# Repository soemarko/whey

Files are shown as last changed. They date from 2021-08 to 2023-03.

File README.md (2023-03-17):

# Whey v2.0

DIY coffee scale / load cell controller.

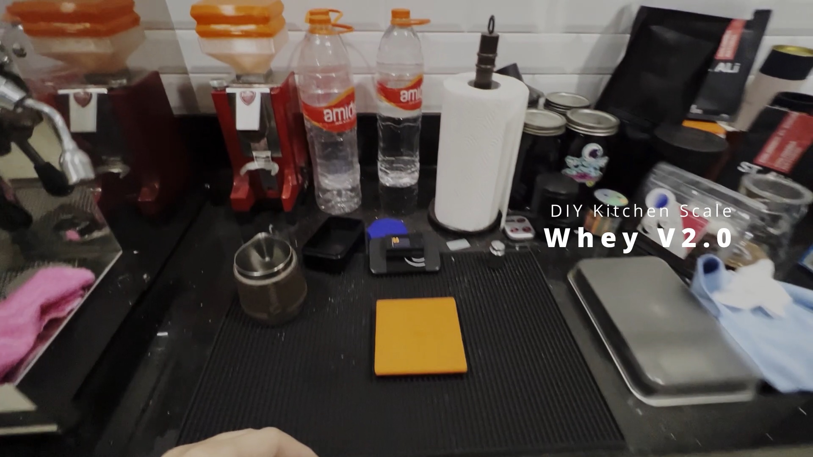
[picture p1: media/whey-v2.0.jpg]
pcb (https://youtu.be/54p8B-DXDt8)


Video of it in action: https://youtu.be/54p8B-DXDt8

Whey v2.0 is a wireless 2-piece hardware that is separated between the sensor plate and the display screen. This project currently uses 500g load cell, with ADS1232 analog to digital converter. It uses ESP-Now to communicate between each microcontrollers. More specific information are available in each directories. The story behind this are available in [my blog](https://soemarko.com/blog/whey-v2.0), everything is linked all the way back to [the very first iteration](https://youtu.be/TIj6iEEiVVo).

### Known Issue

- No battery indicator on the plate -- I just have a powerbank ready when it's not turning on
- ~~TFT_eSPI library only works with the one from [TTGO T-Display repo](https://github.com/Xinyuan-LilyGO/TTGO-T-Display), but won't compile when using the latest one by [Bodmer](https://github.com/Bodmer/TFT_eSPI)~~. Fixed: see Sketch readme.

### Todo

☑ Add readme file in each directories for more specific discussion.\
☐ Battery indicator for the plate?\
☐ Make another plate with 3kg load cell\
☐ Add support for multiple plates (at least 2) to screen

## Updates

- 29 Dec 2021: Officially release v2.0
- 19 Jan 2022: Fix so the low batt indicator doesn't blink when the voltage is right on the edge

## Credits

- ADS1232 library was based on the one by [John Sartzetakis](https://gitlab.com/jousis/ads1232-library)
- ADS1232 Breakout was based on [ESPresso Scale](https://gitlab.com/jousis/espresso-scale) (which were also based of the [ADS1232REF](https://www.ti.com/tool/ADS1232REF))

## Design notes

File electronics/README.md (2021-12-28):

# Electronics

## ADS1232 Breakout Board

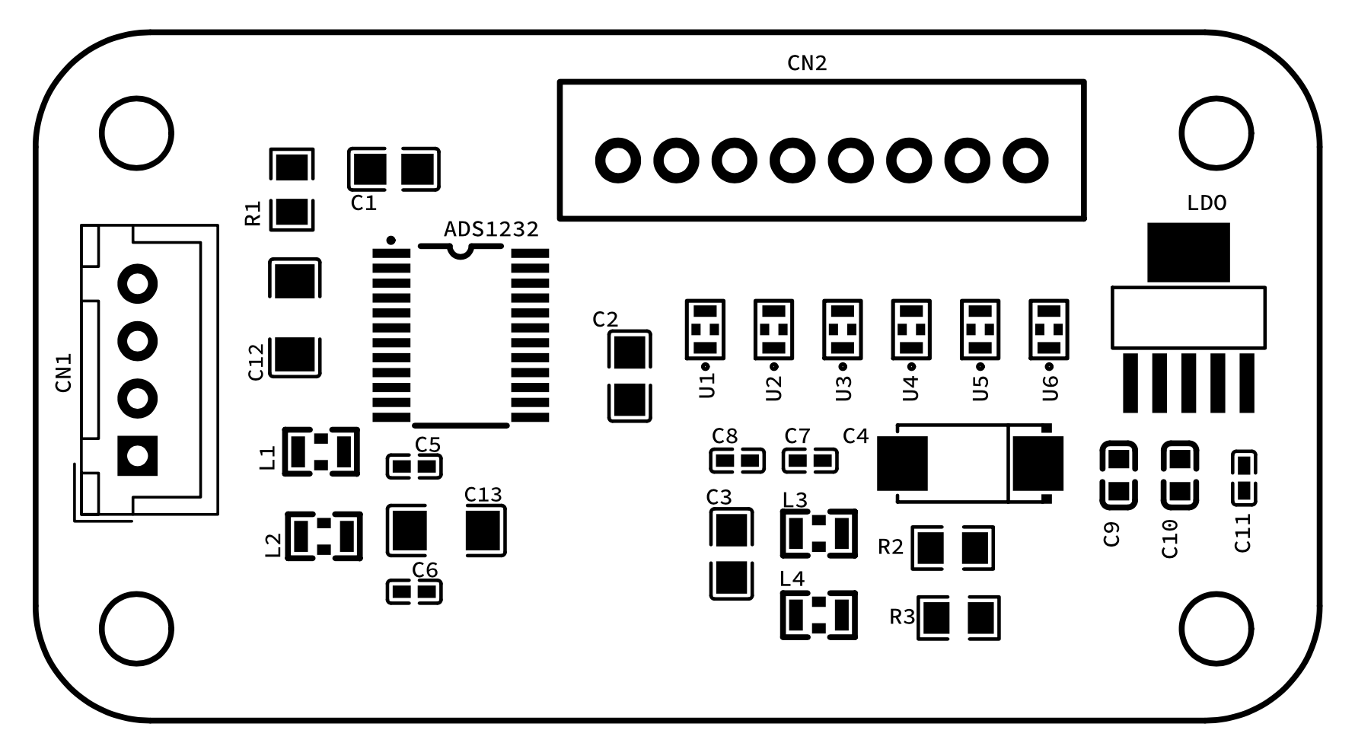
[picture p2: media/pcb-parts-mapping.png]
PCB parts mapping


After receiving my PCB, the only thing that's missing is that I should've label the which wire goes where for the Load Cell input (CN1). Which I have updated in current version of the Gerber file.

That said, let's start from the beginning. CN2 accepts power (right most 2 pins, VCC and GND), and output the ADS1232 to connect to the microcontroller. Thinking back, I should've split this into two 6-pins and 2-pins connection. VCC pin is 5V. The power go straight to LDO to drop it into a very low noise 3.3V which power the rest of the board.

Then we have RC filter for ADS1232 reference power (REFN and REFP), another RC filter for the load cell output. Then we have feed through caps for the ADS1232 outputs.

That's all for this circuit. I can make it a lot smaller, tighen the gaps here and there. Anyway I think it's pretty good for my first fabbed PCB. For the future version, if I ever make one, it'll be all build in. The ESP32, Linear regulator, charging circuit with under and over voltage protection, the whole shebang. Maybe.

## Batteries

Using LiPo battery for both. For the screen, I'm using 503450 1000mAH battery because it's what the enlosure was designed for. I didn't design the screen case. And I'm using J5019 (voltage booster + battery charger) as the battery manager for the sender, boosted up to 5V. It manages the battery charging. At somepoint I might make something with battery level indicator. For them moment, I just keep using it until it won't turn on anymore.

## Load Cell

At this point I am just using a $10 500g load cell. I have a size limitation because I want a better scale, better workflow for my espresso brew. I'll make another plate with 3kg load cell. There I don't have a maximum size limit, in fact I need it to fit my 6-cup Chemex.

## Putting it together

### Receiver / Screen

It's basically stand-alone ESP32 if you use the TTGO T-Display. Otherwise you'll need at least a screen and two buttons and then just adjust the sketch. Take note of the ESP-Now address from Serial monitor and pop it to the sender 

### Sender / Plate

The way I set mine up is LiPo battery -> J5019 -> on/off switch -> ESP -> ADS1232 -> Load cell. I am using a discontinued ESP8266 board, Digistump Oak, but really any ESP board will do. Where the things connect should be obvious from the board, and in theory any pins should work for the ADS, however during my testing some pins (especially the SCLK pin) doesn't work until I switched it around.

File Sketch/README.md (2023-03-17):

# Arduino Sketch

## Receiver / Screen

At minimum you'll need a screen, and two buttons. I'm using TTGO T-Display to avoid building anything, print the enclosure, and superglue magnets behind it and call it a day. After flashing the sketch, take note of the ESP-Now address.

### Button 1 / Top / Pin 35

- Single click: tare
- Click and hold: re-calibrate (I'm using 100g known weight, adjust the `KNOWN_WEIGHT` in file `espnow.ino`)
- Double click: deep sleep

### Button 2 / Bottom / Pin 0

- Single click: start / pause timer. Timer start at -3 and counting up, this is to give me time to do other things and still able to start the brew at 00:00.
- Click and Hold: reset timer.
- Double click: N/A

### Known Issue

When using the TTGO T-Display, if you're using the latest TFT_eSPI library by Bodmer instead of the one from TTGO T-Display repo, don't forget to set the `User_Setup_Select.h` file. Remove / comment out line 22 `//#include <User_Setup.h>`, then uncomment line 53 `#include <User_Setups/Setup25_TTGO_T_Display.h>`. Then everything should compile normally.

## Sender / Plate

Update the sketch with the pins you're using for the ADS1232 (line 20-25). Insert the screen address (line 8). Create a new file named `wificreds.h` for OTA (over the air) update. Upon finishing the build, you'd no longer have access to the microcontroller. This will make updating / changing things much easier than dismantling the whole thing to reflash.

For OTA update, just connect to the same wifi as the scale, and go to `http://whey-sender.local/update` to flash a new one.

To create a new firmware for flashing, from Arduino IDE toolbar, Sketch > Export compiled Binary. Or cmd + option +S.

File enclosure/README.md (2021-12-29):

# Enclosure

## TTGO T-Display

I'm using it to simplify things. The STL is from https://www.thingiverse.com/thing:4843426 and I also use that exact LiPo battery.

## Plate

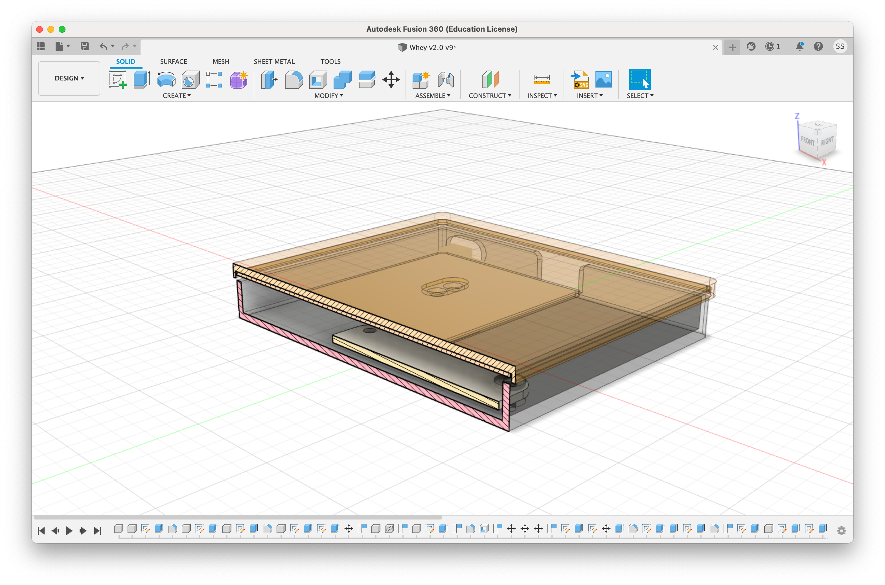
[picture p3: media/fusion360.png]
enclosure


This is a tricky one. I haven't been able to remove wobbles when doing everything in plastic. So I got myself a cheapo, bottom of the barrel, 3018 CNC machine, and just slowly machine 2mm aluminium. The containing folders are the materials I used for my plate.

### Aluminium

Since it is a dinky little CNC machine, I'm not comfortable of machining a plate and wedge as a singular piece. So I just split it into two. Machine a couple of wedges (top and bottom), the smaller plate is the bottom one, which is just superglued onto the bottom case. The bigger plate is for the top one, just wedged in with top plastic and screwed together.

### Plastic

Everything should be obvious. The empty space towards the back is where my microcontroller sit. I just hotglue things to the case so they don't move around. And hotglue the wires so it won't push up against the top plate.

I just use 2 screws on the side to secure the ADS board because the battery I'm using is larger than expected. So part of the battery will just wedged under the other side of the ADS board.

### TPU

I added a TPU cover to protect against splashes. Looking back, I don't think I need to make a plastic top cover. Just machine a larger aluminium top plate and cover it with TPU. This is how I plan on making the 3kg plate.

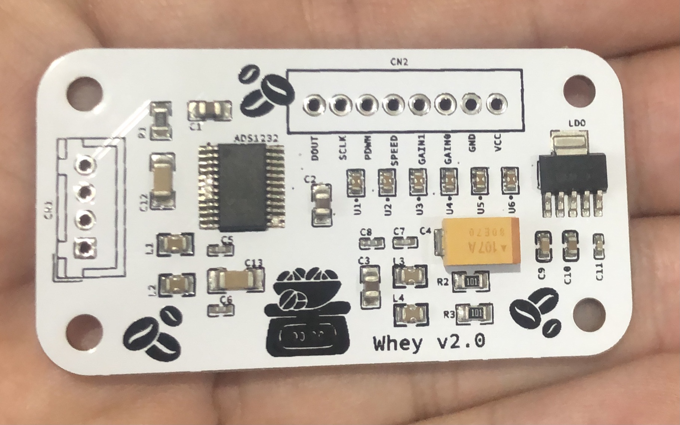
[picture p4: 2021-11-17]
media/pcb.jpeg

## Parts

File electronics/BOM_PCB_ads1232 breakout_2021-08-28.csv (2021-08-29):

ID | Name | Designator | Footprint | Quantity | Manufacturer Part | Manufacturer | Supplier | Supplier Part | Price
1 | TPS79533DCQR | LDO | SOT-223-6_L6.5-W3.5-P1.27-BR | 1 | TPS79533DCQR | TI | LCSC | C28669 | 1.564
2 | NFM18CC101R1C3D/BKN | U1,U2,U3,U4,U5,U6 | FILTER-SMD_3P-L1.6-W0.8-L_NFM18CC223R1C3D | 6 | NFM18CC101R1C3D/BKN | Murata Electronics | LCSC | C184122 | 0.139
3 | 2.2uF | C9,C10 | C0603 | 2 | GRM188Z71E225KE43D | Murata Electronics | LCSC | C415535 | 0.078
4 | 10nF | C11 | C0402 | 1 | CC0402KRX7R0BB103 | YAGEO | LCSC | C527014 | 0.006
5 | ADS1232IPW | ADS1232 | TSSOP-24_L7.8-W4.4-P0.65-LS6.4-BL | 1 | ADS1232IPW | TI | LCSC | C27919 | 13.13
6 | 2.2uF | C1,C2 | C0805 | 2 | GRM219R71C225KE15D | MuRata | LCSC | C86034 | 0.074
7 | 2.2uF | C3 | C0805 | 1 | GCM21BR71C225KA64L | MuRata | LCSC | C126589 | 0.047
8 | 100uF | C4 | CAP-SMD_L6.0-W3.2-R-RD | 1 | 593D107X9010C2TE3 | VISHAY | LCSC | C167094 | 0.367
9 | 100pF | C5,C6,C7,C8 | C0402 | 4 | CC0402FRNPO9BN101 | YAGEO | LCSC | C327198 | 0.008
10 | 100nF | C12,C13 | C1206 | 2 | GRM31C5C1H104JA01L | MuRata | LCSC | C97946 | 0.14
11 | JST 2.54-4P | CN1 | JST-XH-04P | 1
12 | JST 2.54-8P | CN2 | JST 2.54-8PIN | 1
13 | NFM21PC105B1C3D | L1,L2,L3,L4 | FILTER-SMD_3P-L2.0-W1.2-L | 4 | NFM21PC105B1C3D | MuRata | LCSC | C92518 | 0.096
14 | 47K | R1 | R0805 | 1 | ERJP06F4702V | PANASONIC | LCSC | C441989 | 0.034
15 | 100 | R2,R3 | R0805 | 2 | ERA6AEB101V | PANASONIC | LCSC | C445646 | 0.07

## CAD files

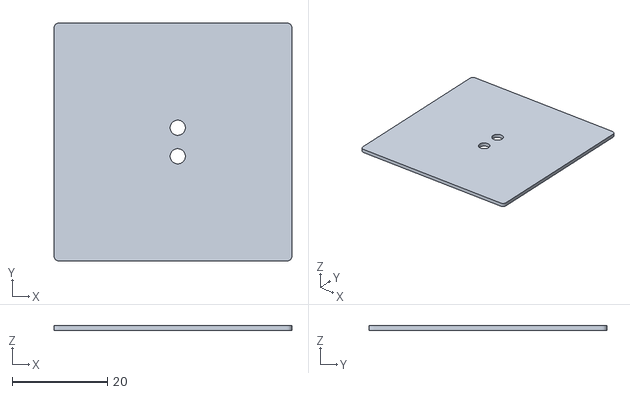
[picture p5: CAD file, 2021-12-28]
enclosure/plate/Aluminium/plates_Load Cell 500g v6_Top_plates.stl
50.0 x 50.0 x 1.00

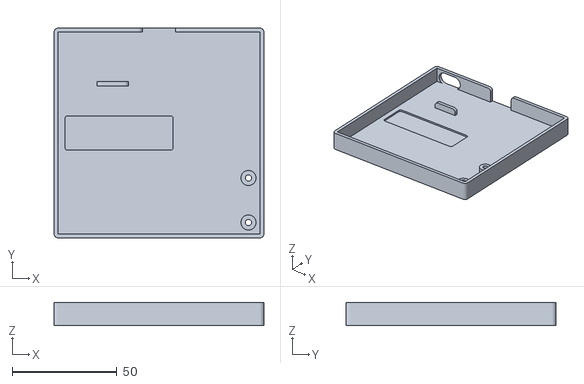
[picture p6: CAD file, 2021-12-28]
enclosure/plate/Plastic/case_Whey v2.0 v9_bottom_1_Body1_bottom.stl
100.0 x 100.0 x 11.0

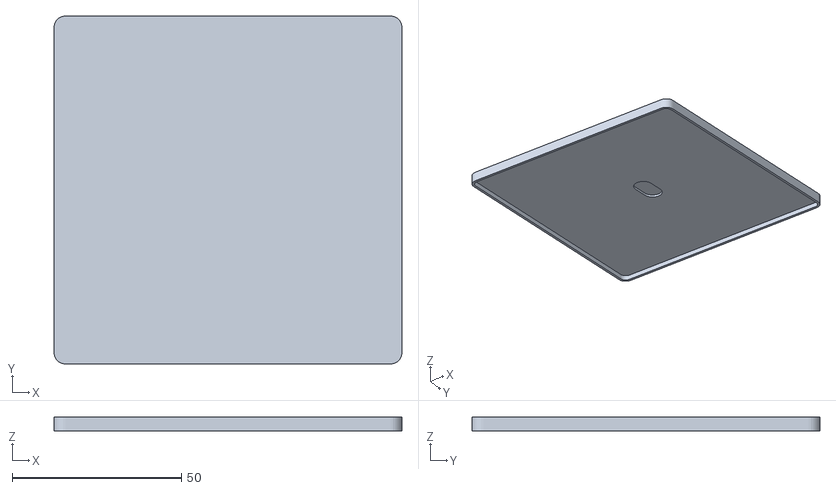
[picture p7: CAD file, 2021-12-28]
enclosure/plate/TPU/case_Whey v2.0 v9_cover_1_Body1_cover.stl
102.8 x 102.8 x 4.00

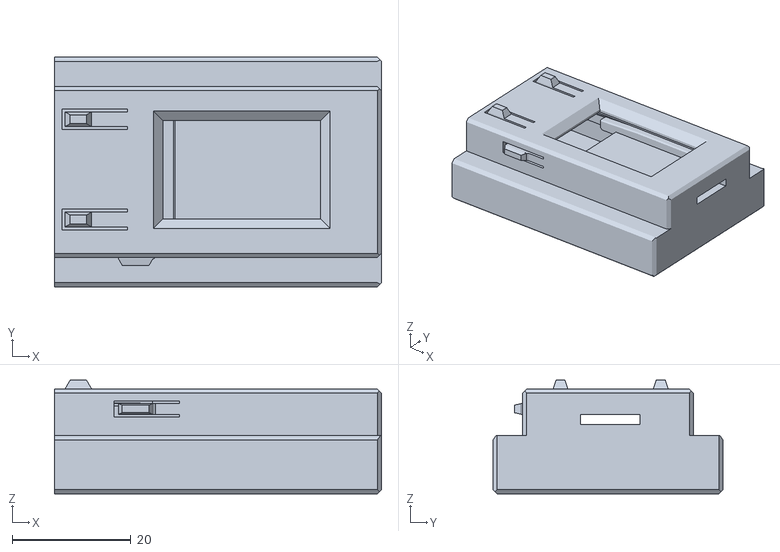
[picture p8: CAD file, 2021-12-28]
enclosure/ttgo t-display/esp32-ttgo-lipo503450-body.STL
55.0 x 38.8 x 19.1

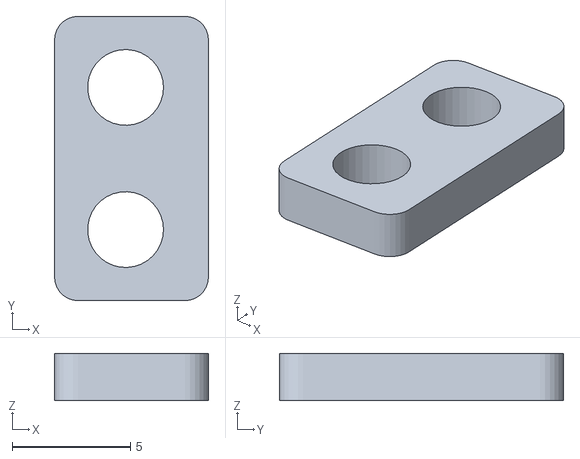
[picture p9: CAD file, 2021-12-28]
enclosure/plate/Aluminium/plates_Load Cell 500g v6_wedge_plates.stl
6.50 x 12.0 x 2.00

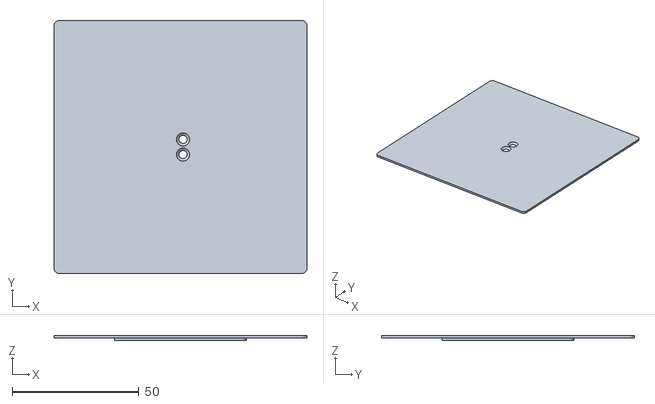
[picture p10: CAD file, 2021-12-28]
enclosure/plate/Plastic/case_Whey v2.0 v9_top_1_Body1_top.stl
100.0 x 100.0 x 2.00

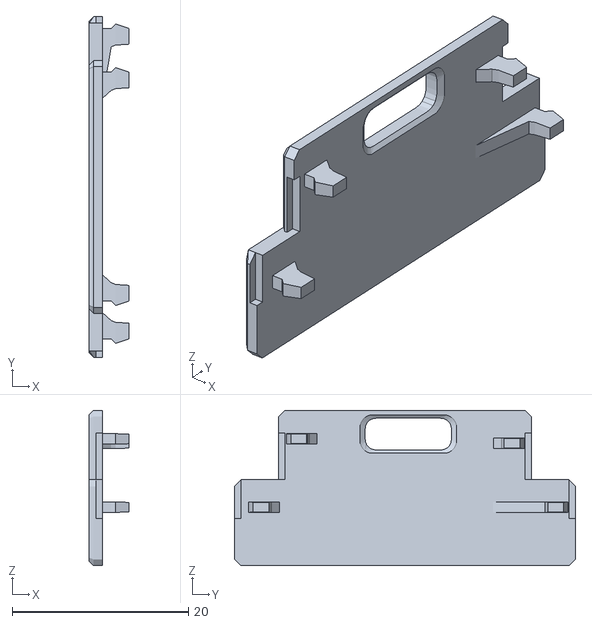
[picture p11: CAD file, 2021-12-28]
enclosure/ttgo t-display/esp32-ttgo-lipo503450-cap.STL
4.50 x 38.8 x 17.6

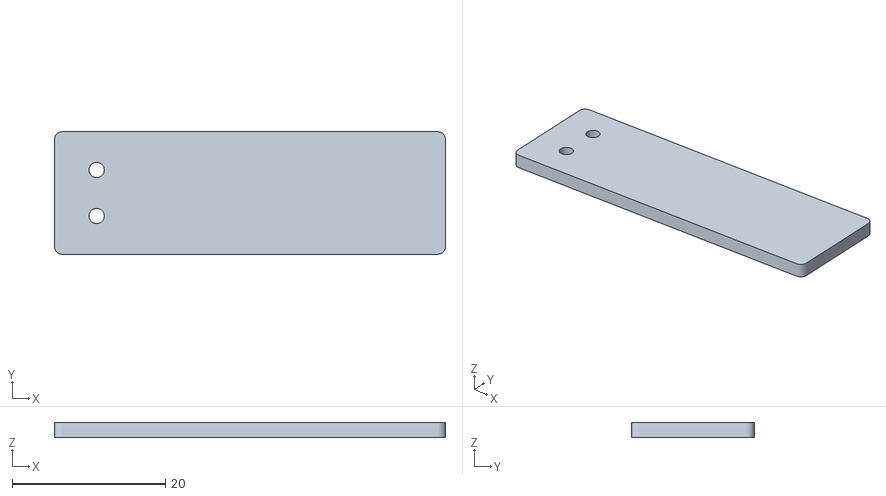
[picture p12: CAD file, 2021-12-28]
enclosure/plate/Aluminium/plates_Load Cell 500g v6_bottom_plates.stl
51.0 x 16.0 x 2.00

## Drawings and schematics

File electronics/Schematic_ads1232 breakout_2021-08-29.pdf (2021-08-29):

Input / Output | ADS1232

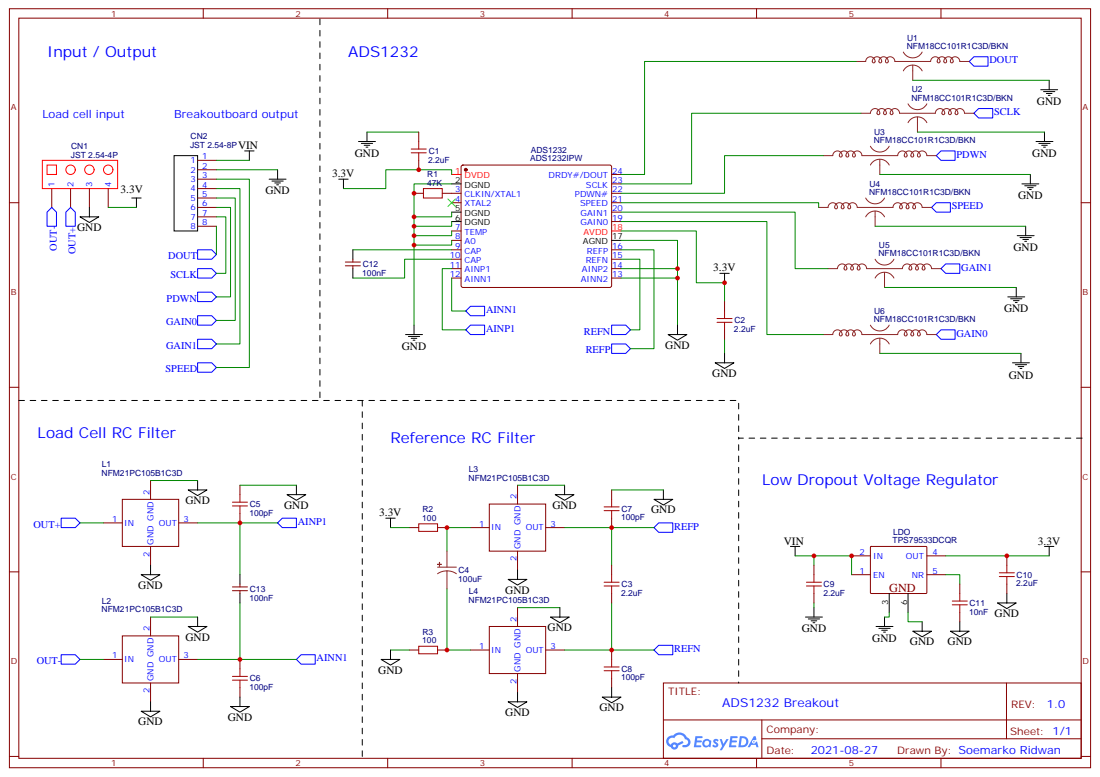
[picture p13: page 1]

Reference RC Filter Load Cell RC Filter

Low Dropout Voltage Regulator

Drawn By: Soemarko Ridwan

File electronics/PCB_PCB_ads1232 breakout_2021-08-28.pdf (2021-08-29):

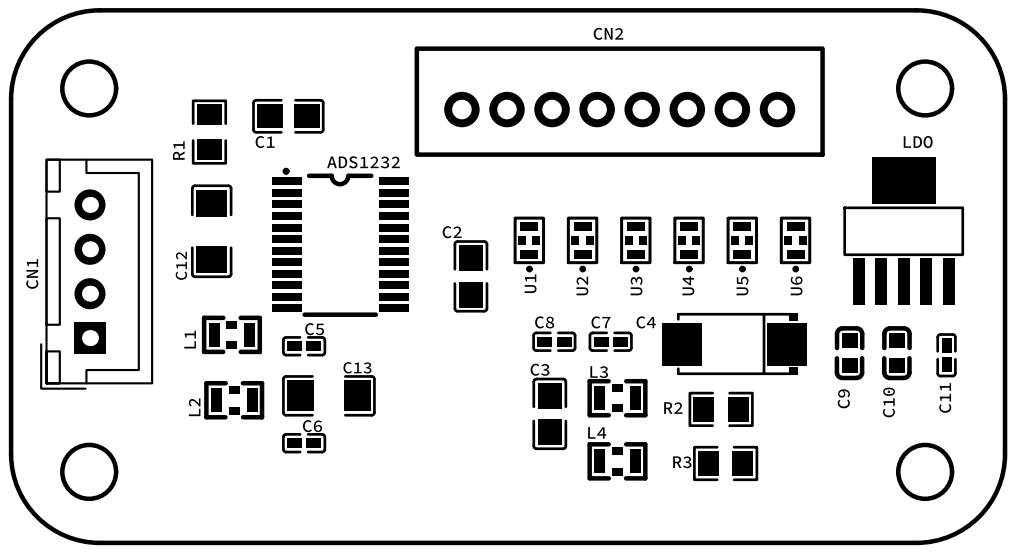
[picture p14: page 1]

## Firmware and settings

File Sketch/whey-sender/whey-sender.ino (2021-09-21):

#include <ESP8266WiFi.h>
#include <espnow.h>
#include "ADS1232.h"

// ***************** ESP Now

uint8_t broadcastAddress[] = {0x4C, 0x11, 0xAE, 0xA5, 0xE5, 0x34};

typedef struct struct_message {
    int32_t value;
} struct_message;

struct_message myData;

// ***************** Scale

#define _samples 10

#define _dout_pin 13  // P7 (pins on Oak Digistump silkscreen)
#define _sclk_pin 14  // P9
#define _pdwn_pin 12  // P8
#define _speed_pin 15 // P6
#define _gain0_pin 4  // P5
#define _gain1_pin 3  // P3
#define _a0_pin 0
#define _temp_pin 0

ADS1232 scale = ADS1232(_pdwn_pin, _sclk_pin, _dout_pin, _a0_pin, _speed_pin, _gain1_pin, _gain0_pin, _temp_pin);

void setup() {
  // Init Serial Monitor
  Serial.begin(115200);
 
  // Set device as a Wi-Fi Station
  WiFi.mode(WIFI_AP_STA);

  // Init ESP-NOW
  if (esp_now_init() != 0) {
    Serial.println("Error initializing ESP-NOW");
    return;
  }
  
  esp_now_set_self_role(ESP_NOW_ROLE_CONTROLLER);
  esp_now_add_peer(broadcastAddress, ESP_NOW_ROLE_SLAVE, 1, NULL, 0);

  ota_setup();
  
  scale.begin();
  delay(100);

//  randomSeed(analogRead(0));
}
 
void loop() {
  // Set values to send
//  myData.value = random(2147483647);
	myData.value = scale.readRaw(_samples);

  // Send message via ESP-NOW
  esp_now_send(broadcastAddress, (uint8_t *) &myData, sizeof(myData));

  Serial.println(scale.readUnits(_samples));

	ota_loop();
//  delay(250);
}

/* Calibrate offset. For testing without screen. */

void calibrate() {
	scale.calFactor = 1.0;

	int32_t offset = scale.readRaw(_samples);

	Serial.println("Calibrating");

	for(int i=9; i>=0; i--) {
		Serial.println(i);
		delay(1000);
	}

	scale.calFactor = (scale.readRaw(_samples) - offset) / 100.0;
	Serial.println("done");
	delay(1000);
}

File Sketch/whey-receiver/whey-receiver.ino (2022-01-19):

#include <TFT_eSPI.h>
#include <SPI.h>

// ***************** TIMER

bool timeStart = false;
volatile int seconds = -4;
hw_timer_t * timer = NULL;
portMUX_TYPE timerMux = portMUX_INITIALIZER_UNLOCKED;

void IRAM_ATTR onTimer() {
	portENTER_CRITICAL_ISR(&timerMux);
	seconds += 1;
	portEXIT_CRITICAL_ISR(&timerMux);
}

int precision = 1;
float weight = 0.0;

void setup() {
  // Initialize Serial Monitor
  Serial.begin(115200);
  
  espnow_setup();

  screen_init();
  button_init();

	timer = timerBegin(0, 80, true);
	timerAttachInterrupt(timer, &onTimer, true);
	timerAlarmWrite(timer, 1000000, true);
}

void loop() {
  espnow_loop();
  
	button_loop();
	screen_loop();

	if(timeStart) timerAlarmEnable(timer);
	else timerAlarmDisable(timer);
}

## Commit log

2020-10-19 add voltage divider image
2021-08-29 v2.0 initial commit
    [BOM_PCB_ads1232 breakout_2021-08-28.csv, PickAndPlace_PCB_ads1232 breakout_2021-08-28.csv]
2021-09-14 v2 update 2
    [Controller_body.stl, Controller_lid.stl, Scale_bottom.stl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]
2021-09-21 remove v1. use tag instead
    [Controller_body.stl, Controller_lid.stl, Scale_bottom.stl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]
2021-11-17 prototype done
2021-12-28 official release of v2.0
    [case_Whey v2.0 v9_bottom_1_Body1_bottom.stl, case_Whey v2.0 v9_cover_1_Body1_cover.stl, case_Whey v2.0 v9_top_1_Body1_top.stl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]
2021-12-29 updated enclosure readme
2022-01-19 fix low batt indicator issue on ttgo t-display
    [ttgo_tdisplay.ino, whey-receiver.ino]
